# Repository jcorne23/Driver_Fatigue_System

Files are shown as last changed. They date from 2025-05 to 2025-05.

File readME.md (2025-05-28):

# Driver Fatigue System

An integrated driver monitoring system using OpenCV and dlib on a Raspberry Pi to track fatigue through eye and mouth aspect ratios, calculating a running fatigue score based on blink and yawn patterns. The ESP32-CAM streams live video over a custom webserver and displays real-time fatigue data via OLED. An onboard MQ3 sensor supports alcohol detection through a guided breathalyzer test, calibrated using controlled samples and baseline readings. A Flask server coordinates system behavior and enables mobile-based interaction, including optional emergency alert triggers—no internet required. Each respective folder has the code associated with each device with the inclusion of schematics and PCB files. Made and designed by Julio Cornejo and Vincent Ng. 

- [Design Document (PDF)](docs/design_document.pdf)
- [Engineering Notebook](docs/engineering_notebook.md)
- [Final Paper (PDF)](docs/final_report.pdf)

                                                Click the thumbnail to watch the demo!
  
 Click to watch demo (https://drive.google.com/file/d/1akUV6YvoVE6YVaj2TsC6vIiu5VjOl5T-/view?usp=sharing)

- [Video Demo 2](https://drive.google.com/file/d/1_dD5bf3DfNFZJkOF3wCcVmGohEKaDvxr/view?usp=sharing)

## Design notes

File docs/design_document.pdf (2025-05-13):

# Driver Fatigue System

## ECE445 Design Document - Spring 2025

Project # 76
Julio Cornejo
Vincent Ng

Professor: Arne Fliflet
TA: Maanas Agrawal

## Contents

Subsystem 1: Blood Alcohol Concentration System

### 1. Introduction

Problem:
When driving for prolonged amounts of time, some key body movements and facial changes can be made due to drowsiness. The drowsiness, if unmonitored, can pose dangerous conditions for other drivers and the drivers themselves. Intoxication while driving is also a rampant issue; there is no universal breathalyzer that prohibits driving based on BAC. I propose this device that uses facial recognition, eye-level detection sensors, and cameras to detect symptoms of fatigue along the road while also prohibiting intoxicated drivers from proceeding to drive. This device can monitor head position, yawns, and register long blinks. It can also track the driving duration and eventually register all these symptoms if it detects fatigue. Once enough triggers are set, an app interface can assess your tiredness or driving incapability via WiFi transmission. It can suggest and locate the nearest rest stop or call emergency contacts (set by the user). When specific drowsiness scores are reached, the user's BAC and live drowsiness rating will be displayed with in-house buzzer systems.

Solution:
The system revolves around an algorithm that makes use of a variety of sensors and cameras. One is a breathalyzer that measures the blood alcohol concentration of the driver. Using the software, we monitor the live value and set triggers to call emergency contacts and monitor until a safe concentration for resumable driving. Drowsiness and tiredness can be detected in various ways ranging from yawn frequency, long blinks, and head tilts. They happen suddenly. Most traditional cars use your position in a lane to track tiredness. Tracking head movement and analyzing the face for more key indicators precisely provides more information that can be essential to identify when a driver needs to step away from the wheel and request a ride elsewhere. The PCB can be housed in a small, compact shape like a cube that sits over any dashboard with detachment features to trigger the BAC sensor correctly.

Visual Aid:

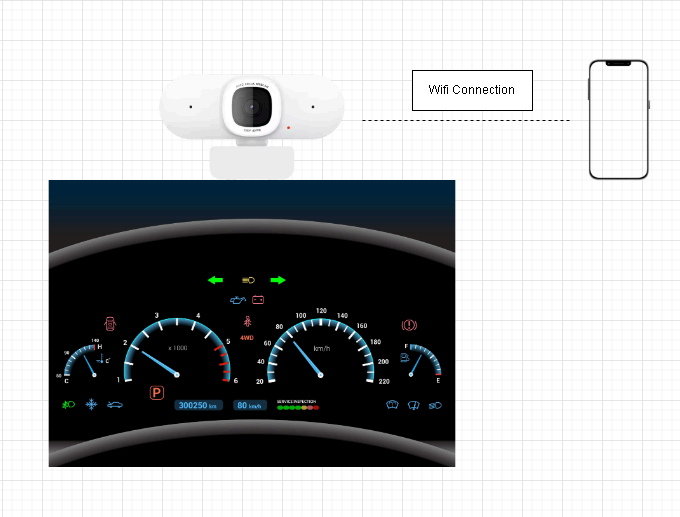
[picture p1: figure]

S
Figure 1: Simple Device Overview High-Level Requirements:
- Driver Inactivity Detection Accuracy: The system must detect eye closure and blink duration with at least 90% accuracy, using an EAR threshold of 0.2 for detecting closed eyes and registering blinks that last ≥15 frames as prolonged closures. The false positive rate for open eyes must remain below 5%.
- BAC Measurement Precision: The device must measure Blood Alcohol Concentration (BAC) with an accuracy of ±1% BAC.
- User Interface Accessibility: The system must provide a mobile/web-based interface that updates drowsiness and BAC data in real-time (latency ≤1 second) and helps users contact emergency contacts within 5 seconds when the drowsiness score surpasses a certain threshold.

### 2. Design

Physical Design:
The physical design of our device will be similar to that of a driver facing dash cam. The housing of our design will be a rectangular box made out of plastic, with cutouts for the camera module, display, led, and breathalyzer tube. There will also be a mounting mechanism for the device so that it can sit securely on the drivers dashboard. In the current time frame of the project, we are not yet at the stage of having a prototype built, but once we do, an image will be attached here for reference.

Block Diagram:

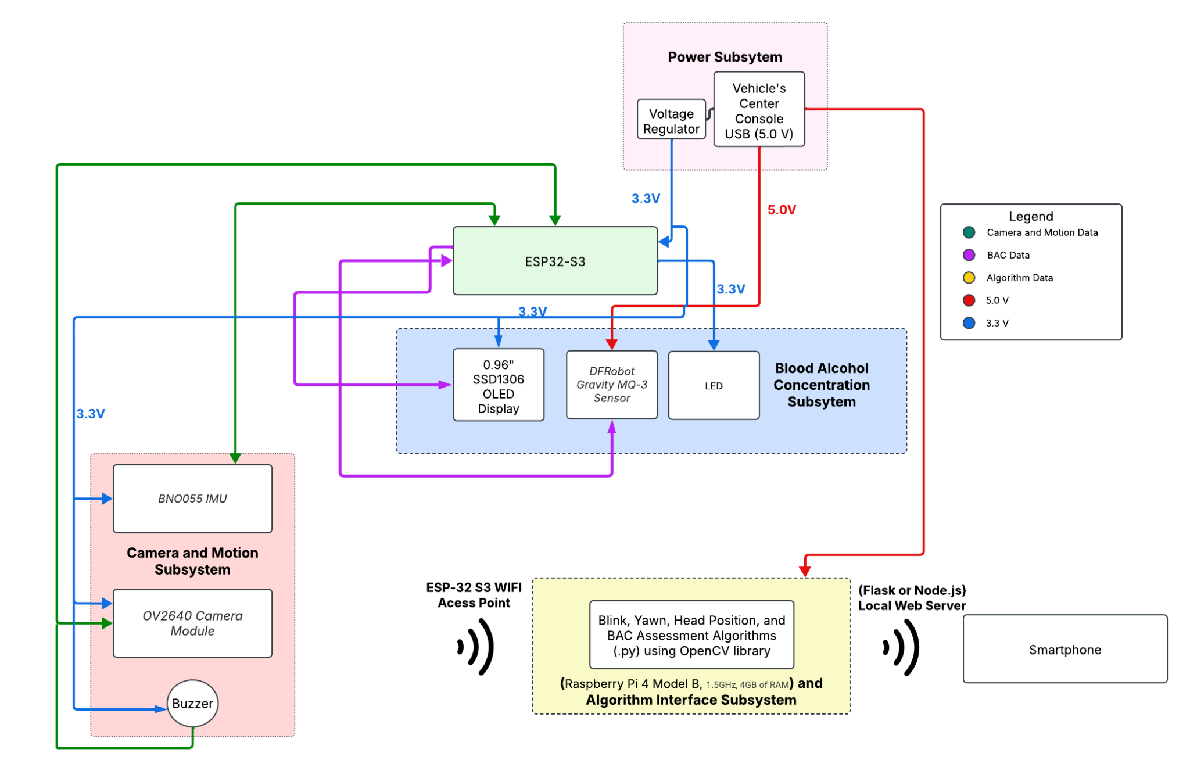
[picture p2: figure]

Figure 2: Diagram of How Each Subsystem is Connected

Subsystem Overview:

Subsystem 1: Blood Alcohol Concentration System
Overview:
The functionality of this subsystem revolves around the MQ-3 breathalyzer sensor responsible for measuring the BAC of a potential driver. Accompanying the sensor is logistical device tools such as a display and LED. This module is connected to the ESP32 microcontroller and communicates directly with our designed algorithm for an automated emergency notification system if intoxication is detected. The BAC will also be locally displayed on the unit's OLED screen. A light will light blue when the device is ready to test an individual’s BAC.

Requirements:
- The device must measure Blood Alcohol Concentration (BAC) with an accuracy of ±0.01% BAC, within a detection range of 0.00% - 0.20% BAC.
- The device must ensure the baud rate transmission is 9600 for the MQ-3’s functionality.
- The LED accurately reflects the readiness and warm-up time of the MQ-3 to provide accurate measurements.

Requirements and Verification Table:
Requirements | Verification
- The device must measure BAC with an accuracy of ±0.01% BAC within a detection range of 0.00% - 0.20% BAC. | ● Perform calibration tests using known alcohol concentrations and compare readings with a certified breathalyzer. ● Cross-checking each of the individual MQ-3 sensors since we ordered a few for faultiness.
- The device must maintain a baud rate of 9600 for MQ-3 communication. | ● Monitor serial transmission using an oscilloscope to verify correct baud rate operation.
- The LED should accurately reflect the readiness and warm-up time of the MQ-3. | ● Measure time from power-on to ready-state using a stopwatch and validate against the MQ-3 datasheet specifications.

Subsystem 2: Power System
Overview:
Our primary power source for our power subsystem comes directly from a car's center console. Most cars have USB ports that provide 5V of power. Coupled with a voltage regulator to step down to 3.3V, we can power our ESP32 and sensor/camera modules. The MQ-3 is powered directly by the 5V source.

Requirements:
- Maintain overall voltage stability within a tolerance of 0.1V (+/-).
- Successful step-down conversion to 3.3V for smooth operation of the BNO055 IMU (Head position sensor), OV2640 Camera Module, SSD1306 OLED Display, and LED.
- Must provide consistent and stable 5V to operate the MQ-3’s critical sensor.

Requirements and Verification Table:
Requirements | Verification
- Maintain overall voltage stability within a tolerance of ±0.1V. | ● Measure voltage fluctuations using a digital multimeter (DMM) under different load conditions.
- Ensure successful step-down conversion to 3.3V for all necessary components. | ● Use a DMM to verify stable 3.3V output under normal operating conditions.
- Provide a consistent and stable 5V output for MQ-3 operation. | ● Test voltage stability under varying load conditions and monitor power fluctuations using an oscilloscope.

Subsystem 3: Camera and Motion System
Overview:
This subsystem is the most critical component for sensing fatigue. Both sensors, BNO055 IMU for head movement and OV2640 Camera Module for eye blink and yawn detection, are essential inputs for our computer vision algorithm; both sensors are powered by a 3.3V power source and interact and transmit data directly to the ESP32. A buzzer is provided for temporary alertness in emergency-level drowsiness.

Requirements:
- Capable of capturing images with sufficient clarity for detecting blinks and yawns.
- To ensure real-time processing, the camera should interface with the ESP32 and quickly transmit image data via WiFi to the Raspberry Pi.
- The camera should support JPEG image compression for efficient data transfer.
- Minimum image resolution: 640x480 pixels and frame requirement of 30fps.
- Non-intrusive (low dB) buzzer and alert-focused sound.

Requirements and Verification Table:
Requirements | Verification
- Capture images with sufficient clarity to detect blinks and yawns. | ● Evaluate image resolution and sharpness using controlled lighting conditions. ● Sample test of an individual blinking X amount of times in a tets period 60 sec. Compare results with algorithm testing.
- Camera must interface with ESP32 and transmit data via WiFi with minimal latency. | ● Measure transmission delay using a network packet analyzer. ● Compare the speed and algorithm running process with I2C connection before testing with WiFi.
- Support JPEG image compression for efficient data transfer. | ● Verify image file sizes and compression ratios using software analysis.

- Maintain a minimum resolution of 640x480 pixels and 30fps frame rate.
- Capture and analyze sample frames to confirm compliance with the required resolution and frame rate.
- Buzzer should emit a non-intrusive alert sound.
- Measure buzzer sound levels in decibels (dB) using a sound meter. Place the nozzle of the sound meter above the encaving of the active buzzer.
- Most active buzzers can be lowered by attaching a resistor using the correct amount of resistance. Validate with a 1k, 10k, etc. for the optimal db count using a sound meter.

Subsystem 4: Algorithm and User Interface Subsystem
Overview:
This subsystem will handle the processing of all sensor data, run the necessary algorithms to assess drowsiness levels based on eye blink frequency, head movements, and breathalyzer readings, and display the results on a web app accessible from a smartphone. It will
communicate wirelessly with the ESP32 microcontroller via WiFi using a client-server access point connected to the Raspberry Pi to receive real-time sensor and camera data. The algorithm will analyze the data, calculate the drowsiness level, and send this information to the web app via another access point, a web-server host using Flask or, potentially, Node.js as our framework. Using WiFi once more, we can display and manipulate all the data for analytics on the smartphone. The web app will provide a real-time drowsiness score to the user and display analytics.

Requirements:
- Using an efficient algorithm, the system must calculate a fair drowsiness score from real-time data (eye blinks, head movement, BAC levels), providing instant feedback on driver fatigue.
- The ESP32 should transmit drowsiness data via WiFi with a minimum baud rate of 9600 bps.
- The web app should provide real-time feedback on the driver’s drowsiness score, display analytics (e.g., blink frequency, head movement), and send alerts when fatigue levels are critical.

- The system must log drowsiness data for historical analysis and send push notifications or emergency contact alerts when the drowsiness score exceeds a defined threshold. Pi Link (https://www.digikey.com/en/products/detail/raspberry-pi/SC0194(9)/10258781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)

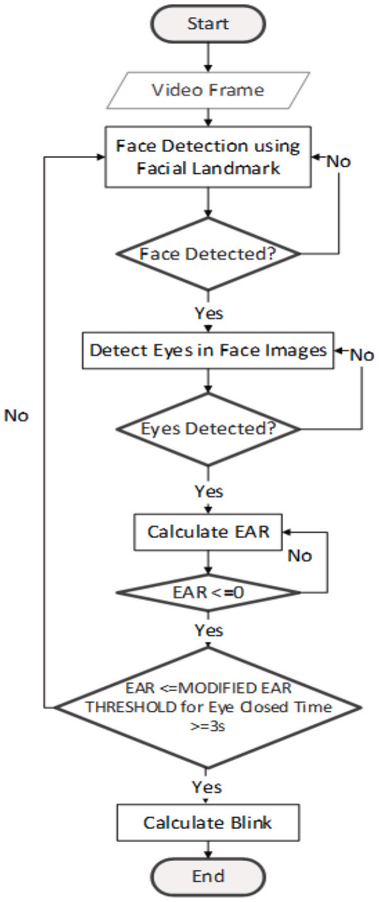
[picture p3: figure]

Figure 3: Flow Chart of EAR algorithm

Requirements and Verification Table:
Requirements | Verification
- Calculate a real-time drowsiness score based on sensor inputs. | ● Validate computed scores against manually analyzed fatigue behavior datasets. ● For test subjects, we can have a self-reported driving quiz where the user assesses a level where they feel incapable
- ESP32 must transmit drowsiness data via WiFi with a baud rate of at least 9600 bps. | ● Monitor WiFi transmission rates using a network packet analyzer.
- Web app should provide real-time
feedback on drowsiness score and analytics.
- Conduct usability tests to ensure data is displayed with minimal delay.
- A user should be able to query into our database to see the times a certain score of their choosing is submitted during their driving times.
- System should log drowsiness data and send emergency alerts when a defined threshold is exceeded.
- Simulate drowsiness conditions and verify proper alert generation and logging.
- Use Twilio API and simulate a call to ourselves via

Tolerance Analysis:
One of this project's most critical and challenging components is the accurate detection of eye closure and blink duration using EAR. The system must reliably differentiate between normal blinking and drowsiness-induced prolonged eye closures while accounting for environmental factors such as low lighting, camera angle variations, and false detections. Reliable measurements are crucial as not to falsely alert drivers when driving on the road.
The Eye Aspect Ratio formula is given below:

P1-P6 are the eye landmarks detected by the OV2640 camera module

We can set the EAR threshold to:
Eyes open: 0.2-0.3
Eyes partially closed: 0.15-0.2
Eyes closed: < 0.15
However, these thresholds are not set in place and can be adjusted once the algorithm testing begins so that we can implement a more refined threshold.
Given our EAR thresholds, we can also register blinks with these conditions:
EAR drops below 0.2 for three consecutive frames (assuming a 30 FPS camera feed).
If EAR remains below 0.2 for more than 15 frames, it is flagged as a sign of drowsiness.

Tolerance Analysis Considerations:
Component Accuracy and Environmental Factors:

Camera Resolution and Precision:
The OV2640 camera module has a resolution of 640x480 pixels at 30 FPS, but low-light conditions may affect its accuracy.
The sensor has an approximate accuracy variance of ±5% in detecting key facial landmarks due to environmental lighting and head orientation.

Measurement Noise and Latency:
EAR calculations rely on landmark detection accuracy, which may fluctuate due to camera latency (typically 10-20 ms per frame under normal conditions).
Noise filtering techniques (e.g., median filtering) will be used to smooth EAR readings to reduce variability.

EAR Threshold Tolerance:
A deviation of ±0.02 EAR from the expected threshold could lead to false positives or missed detections.
A key risk is misclassifying normal long blinks or head tilts as drowsiness. Therefore, we can introduce an adaptive threshold based on the driver's historical blink patterns, adjusting the EAR threshold dynamically.

Weighted Drowsiness Scoring Model:
This is our scoring model that is designed to improve drowsiness detection accuracy by incorporating multiple fatigue indicators. Instead of relying solely on blink duration or frequency, this model assigns different weight values to various fatigue-related behaviors, such as yawning and head tilting, based on their severity and impact on alertness. By aggregating these factors into a single score, the system can more accurately differentiate between temporary fatigue and actual drowsiness. This approach minimizes false positives while ensuring that prolonged drowsiness patterns trigger necessary alerts, making the system more reliable for real-world driving conditions. Whenever a certain drowsiness score threshold is reached, the system will contact the driver’s emergency contact.

The drowsiness score is calculated using a weighted formula shown below:
Assume we monitor over a 60-second window and detect the following:
- Blink Duration: 6 long blinks → High risk
- Blink Frequency: 20 blinks → Moderate risk
- Yawns Detected: 4 yawns → High risk
- Head Tilt Angle: 30° tilt for 5+ sec → Moderate risk
- Head Nods: 2 detected → Low risk

Now, applying the weights that are currency variable and are going to be changing :

Drowsiness Score = (6×4.2) + (20×1.0) + (4×7.5) + (1×10) + (2×5) = (6×4.2) + (20×1.0) + (4×
7.5) + (1×10) + (2×5) = 25.2+20+30+10+10=95.2= 25.2 + 20 + 30 + 10 + 10 = 95.2=25.2+20+30+10+10 = 95.2

### 3. Cost

Cost Analysis:
Note that we are considering the cost of the items with the retail price where we acquired the part, excluding ECE discounts.
Part | Manufacturer | Quantity | Price | Subsystem
Raspberry Pi 4 Model B 2GB | Raspberry Pi Ltd | 1 | $53.99 | Algorithm and Interface
Micro-HDMI Male to HDMI Female Adapter | Microware | 1 | $6.16 | Algorithm and Interface
32GB MicroSD Card | Samsung | 1 | $13.05 | Algorithm and Interface
ESP32-S3 Development Board | HiLetgo | 1 | $16.53 | Algorithm and Interface
OV2640 Camera Module | STMicroelectronics | 1 | $11.99 | Camera and Motion
Active Piezo Buzzer Alarm | GFORTUN | 1 | $0.89 | Camera and Motion
MQ3 Alcohol Sensor Module | Reland Sun | 1 | $2.67 | BAC Concentration
0.96" SSD1306 OLED LCD | HiLetgo | 1 | $6.99 | BAC Concentration
LED | HiLetgo | 1 | $0.89 | BAC Concentration
LD117 Voltage Regulator | STMicroelectronics | 4 | $0.80 | Power Subsystem
Total | | | $116.36

Our project has a heavy computation component relying on algorithm creation and data transfer via WiFi. For this reason, many of the estimated labor hours involve client-server setup, so the ESP-32 and the Pi can efficiently and wirelessly communicate. The algorithms will require extensive image processing, so searching and modifying a functional algorithm is one of the largest time-sinks. Assuming an hourly-paid entry-level engineer position, we take an hourly pay of $45. With a rough estimate of 310 hours based on the schedule and planning, our costs come out to:

Total Cost: Labor Cost + Part Cost = ((310 hours) x ($45) ) + $116.36 = $14066.36

### 4. Schedule

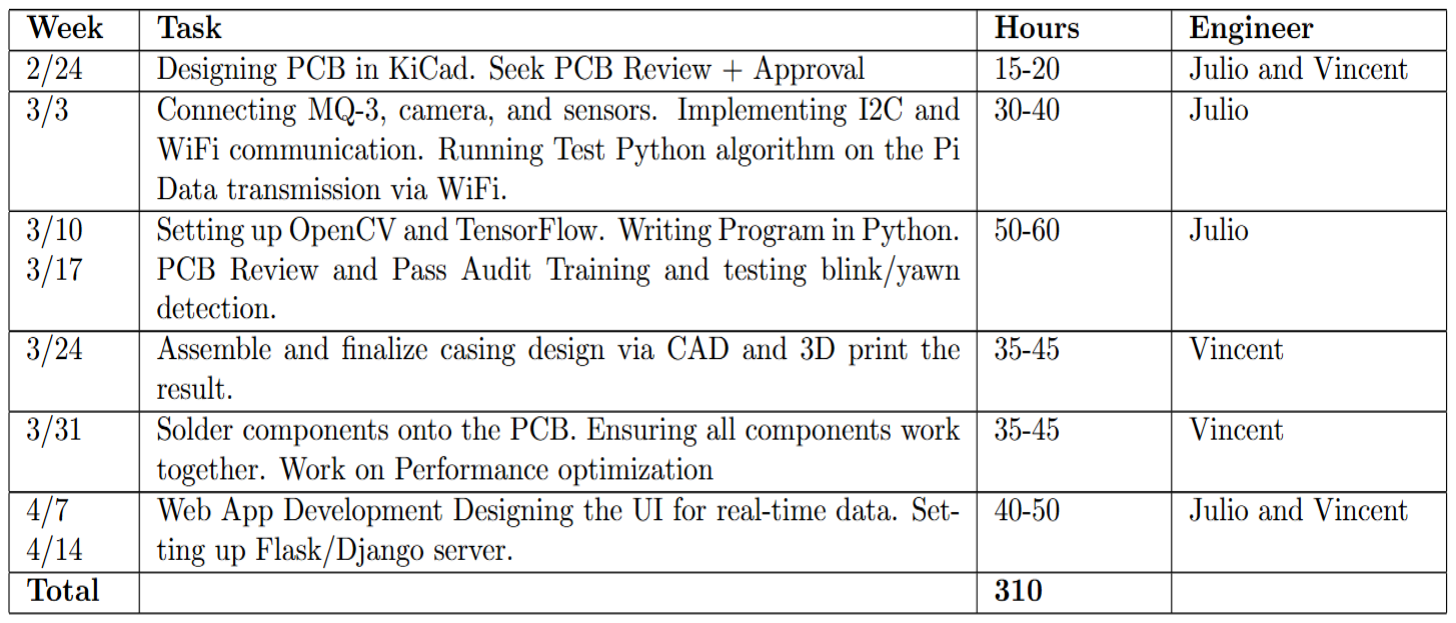
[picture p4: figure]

### 5. Ethics and Safety

Our project's main ethical and safety concerns are privacy and data security.
The system collects sensitive biometric data, including facial recognition patterns, eye movement, and breathalyzer readings. According to the ACM Code of Ethics (Principle 1.6: Respect Privacy), developers must ensure that user data is stored securely and only accessed for its intended purpose. To mitigate potential privacy concerns:
Data will be processed locally on the ESP32-S3 or Raspberry Pi, avoiding unnecessary cloud storage. Encrypted communication protocols (e.g., HTTPS, TLS) will transmit data to the mobile application.

Another ethical concern highlighted by IEEE is Principle 2: Avoid Harm to Others, emphasizing that systems must be designed to avoid discrimination or bias based on race, gender, or disability. We will train our model on a diverse dataset to ensure fairness, including individuals of different ethnicities, backgrounds, and facial features. Not only that, but the EAR threshold will also be adjustable for individuals, allowing for an individualized experience.

Since our device also has a miniature built-in display, we have decided to keep it as minimal as possible to uphold safety guidelines and maintain a safe driving experience. Alerts, buzzer warnings, and the user interface must be designed to minimize distractions.
According to NHTSA guidelines, visual displays should be simple and non-intrusive.
Alerts should not require extended interaction from the driver while operating the vehicle. The buzzer should produce audible but non-alarming signals to avoid panic responses.

### 6. Citations and References

Dewi, C., Chen, R.-C., Jiang, X., & Yu, H. (2022, April 18). Adjusting eye aspect ratio for strong eye blink detection based on facial landmarks. PeerJ. Computer science. https://pmc.ncbi.nlm.nih.gov/articles/PMC9044337/

Pandey, D. (2021, April 21). Eye aspect ratio(ear) and drowsiness detector using dlib. Medium.
https://medium.com/analytics-vidhya/eye-aspect-ratio-ear-and-drowsiness-detector-using -dlib-a0b2c292d706 (https://medium.com/analytics-vidhya/eye-aspect-ratio-ear-and-drowsiness-detector-using-dlib-a0b2c292d706)

Raspberry pi documentation - getting started. Raspberry pi documentation. (n.d.). https://www.raspberrypi.com/documentation/computers/getting-started.html

Shekari Soleimanloo, S., Wilkinson, V. E., Cori, J. M., Westlake, J., Stevens, B., Downey,
L. A., Shiferaw, B. A., Rajaratnam, S. M. W., & Howard, M. E. (2019, September 15). Eye-blink parameters detect on-road track-driving impairment following severe sleep deprivation. Journal of clinical sleep medicine : JCSM : official publication of the American Academy of Sleep Medicine. https://pmc.ncbi.nlm.nih.gov/articles/PMC6760410/

Ucl. (2022, May 6). Blink and you miss it!. UCL News. https://www.ucl.ac.uk/news/2005/jul/blink-and-you-miss-it

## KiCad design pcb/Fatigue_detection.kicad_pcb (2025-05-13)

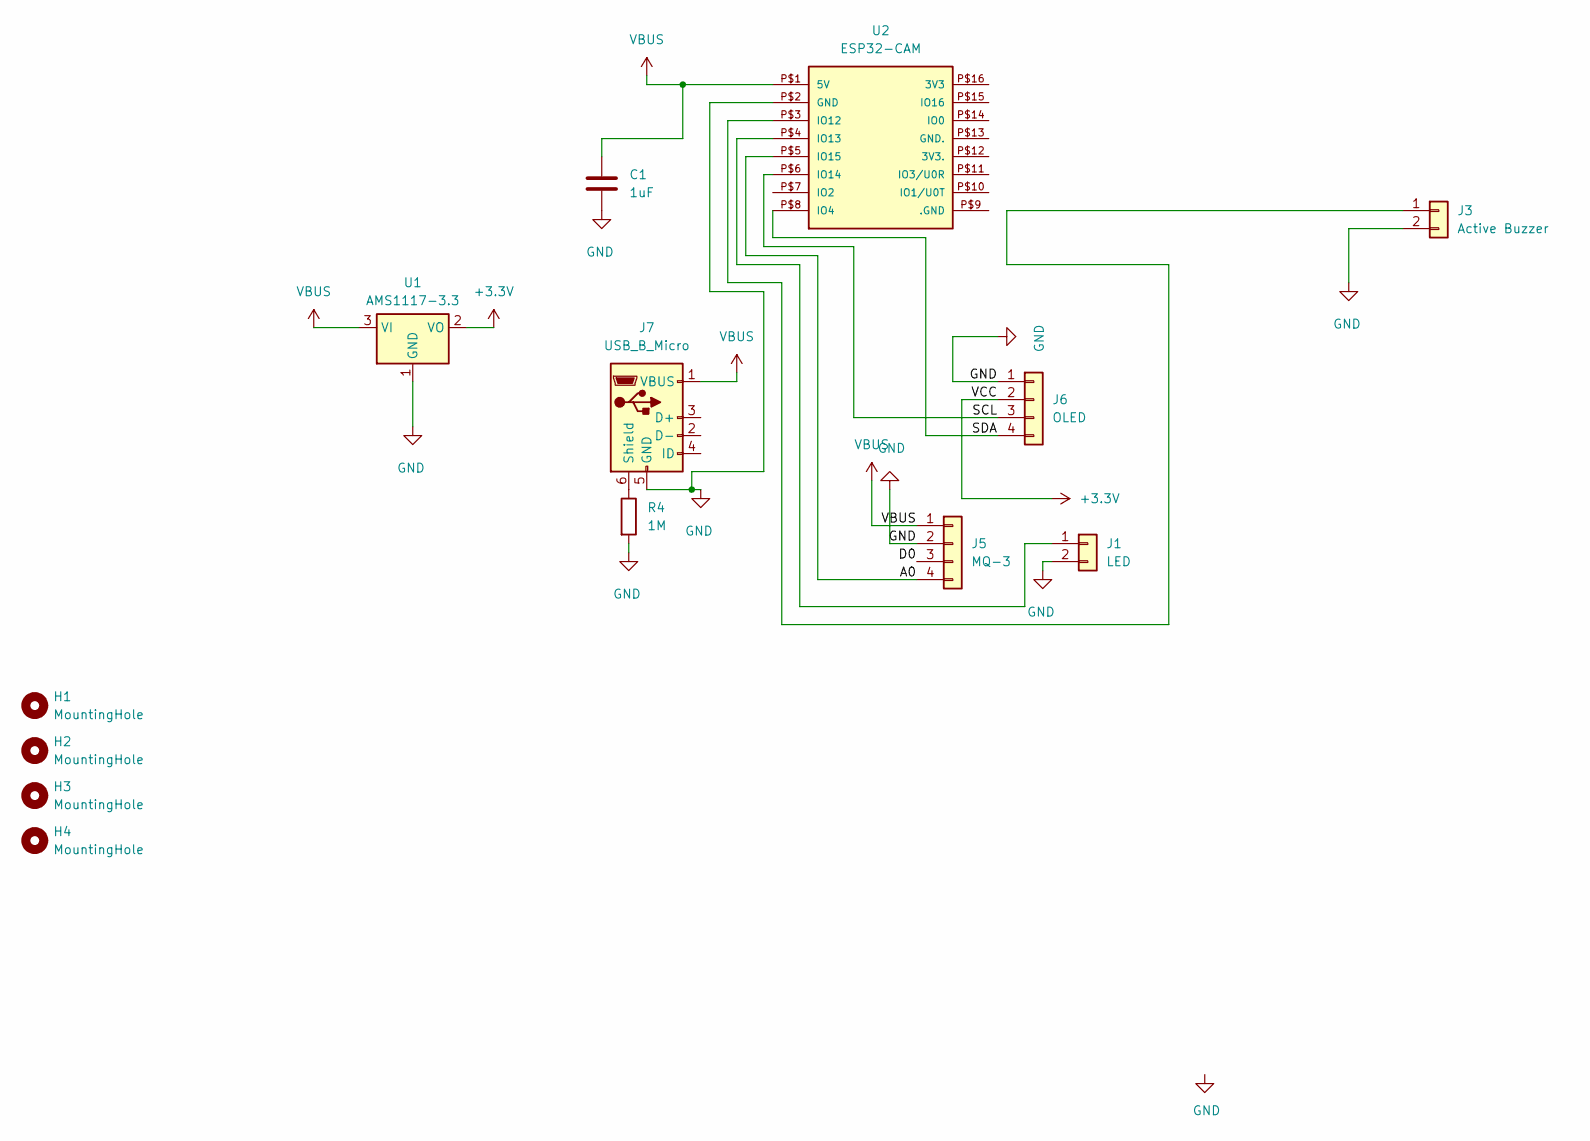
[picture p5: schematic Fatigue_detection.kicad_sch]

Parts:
C1: 1uF; C_0805_2012Metric_Pad1.18x1.45mm_HandSolder
H1, H2, H3, H4: MountingHole; MountingHole_3.2mm_M3
J1: LED; Molex_KK-254_AE-6410-02A_1x02_P2.54mm_Vertical
J3: Active Buzzer; Molex_KK-254_AE-6410-02A_1x02_P2.54mm_Vertical
J5: MQ-3; Molex_KK-254_AE-6410-04A_1x04_P2.54mm_Vertical
J6: OLED; Molex_KK-254_AE-6410-04A_1x04_P2.54mm_Vertical
J7: USB_B_Micro; USB_Micro-B_Amphenol_10118194-0001LF_Horizontal
R4: 1M; R_0805_2012Metric_Pad1.20x1.40mm_HandSolder
U1: AMS1117-3.3; SOT-223-3_TabPin2
U2: ESP32-CAM

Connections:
+3.3V: J6.2, U1.2 (VO)
/A0: J5.4, U2.P$5 (IO15)
/D0: J5.3
/SCL: J6.3, U2.P$6 (IO14)
/SDA: J6.4, U2.P$8 (IO4)
GND: C1.2, J1.2, J3.2, J5.2, J6.1, J7.5 (GND), R4.2, U1.1 (GND), U2.P$2 (GND); also elsewhere on the board
unnamed: J1.1, U2.P$4 (IO13)
unnamed: J3.1, U2.P$3 (IO12)
unnamed 8: J7.6 (Shield), R4.1; also elsewhere on the board
VBUS: C1.1, J5.1, J7.1 (VBUS), U1.3 (VI), U2.P$1 (5V); also elsewhere on the board

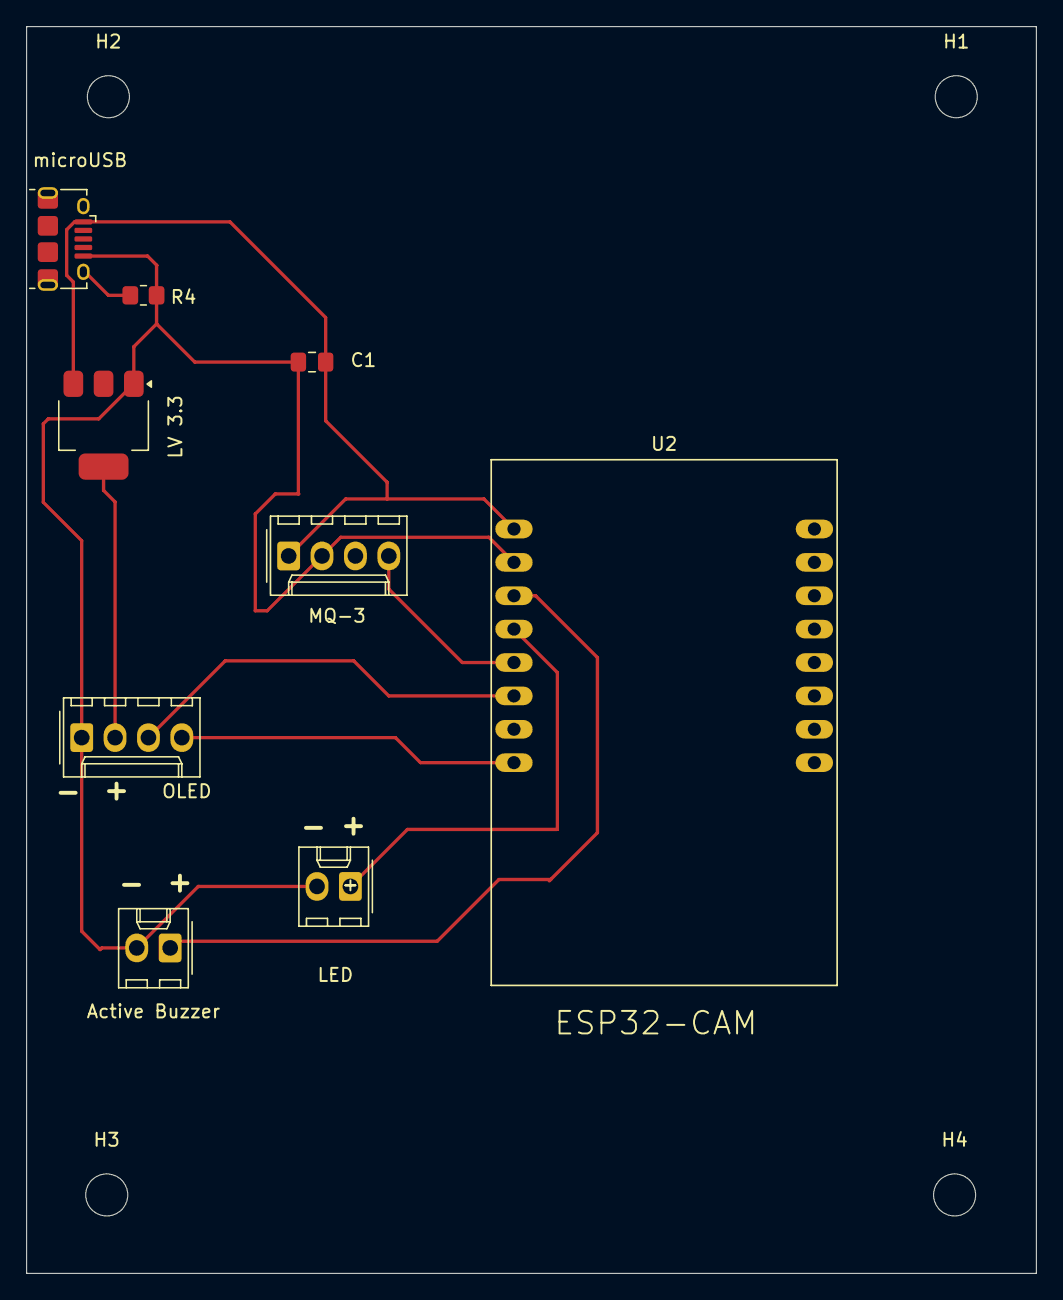
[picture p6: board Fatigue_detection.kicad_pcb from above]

Board: 2 copper layers, 76.8 x 94.9 mm, 13 parts (0 on the bottom side), 9 nets.

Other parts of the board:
microUSB: USB_B_Micro; USB_Micro-B_Amphenol_10118194-0001LF_Horizontal

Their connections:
GND: microUSB.5 (GND); also elsewhere on the board
unnamed 8: microUSB.6 (Shield); also elsewhere on the board
VBUS: microUSB.1 (VBUS); also elsewhere on the board

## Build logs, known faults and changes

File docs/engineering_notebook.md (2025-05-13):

# Driver Fatigue System - Weekly Progress Log
Week 1 Feb 10 - 14 | General Research and Proposal Writing
=========================================================

Sleep-deprived driving is an underappreciated but dangerously common problem. On a recent drive back home from Illinois in my Mustang GT, I experienced firsthand just how severe fatigue behind the wheel can become. Despite having lane assist and blasting music with caffeine in hand, I caught myself swerving repeatedly—my eyelids growing heavier, my focus slipping. There were stretches of road where my eyes were closed for what felt like forever, and I realized I was becoming a serious danger to myself and everyone around me. Rest stops felt untrustworthy, and I had no meaningful way to assess whether I was safe to continue driving.
This experience exposed a real and urgent gap in driver wellness awareness, especially when driving alone for long distances. What I truly needed wasn’t more coffee or loud music; I needed an objective, real-time system that could monitor my condition and help me make smarter decisions before it was too late.
This inspired the development of the Driver Fatigue System—a multi-modal platform designed to track signs of drowsiness, monitor facial fatigue cues like prolonged blinks or yawns, and even detect signs of intoxication. By combining computer vision, real-time feedback, and onboard alerts, this system aims to support drivers in staying safe, informed, and aware of their physical state while on the road.





After identifying the dangers of drowsy driving from personal experience, we began designing a system that could monitor a driver’s alertness in real time. To do this, we needed a mix of physical sensors and wireless communication to assess wellness and deliver feedback quickly. The flowchart we developed became the blueprint for this vision, outlining how each component—camera, sensors, display, and servers—would connect and operate together.
At the heart of the system is the ESP32-S3, which collects sensor data and controls outputs like an OLED display, buzzer, and LED. Powered through a car’s USB port and regulated to 3.3V using an AMS1117, the ESP32 also connects to a DFRobot MQ-3 alcohol sensor and an OV2640 camera module. We initially planned to use a motion sensor (BNO055 IMU), but removed it after determining it was unnecessary.
To handle intensive tasks like image processing, we offloaded blink and yawn detection to a Raspberry Pi 4 running Python scripts and OpenCV, hosted on a Flask web server. Every 30 seconds, the Pi calculates a fatigue score and sends it back to the ESP32 or browser interface. A smartphone hotspot serves as the local network, assigning IPs to both the Pi and ESP32 for fast, local communication.
This system balances local device feedback with server-side intelligence, creating a responsive tool to help drivers assess their condition before it becomes dangerous, all sparked by one tired night on the road.



We begin to seek out parts from the ECE building and using our project funds to outsource on Amazon the items unavailable to us in the building. 

Week 2 Feb 17 - 21 | Project Proposal Review + Inital Design Stage
===================================================================



This schematic represents our initial hardware mockup, developed during the early planning phase of the project. At this stage, we designed around an ESP32-DEVKITC-32E and prioritized including a USB-C connector for modern power delivery and convenience. Power from the USB-C port was stepped down to 3.3V using an AMS1117 regulator to supply the microcontroller and all peripherals. Key components such as the MQ-3 alcohol sensor, OLED display, LED, and buzzer were mapped out and connected directly to available GPIO pins. This early layout gave us full control over pin assignments and served as a foundational reference for system integration.



This image shows our initial PCB layout in KiCad, where we encountered several critical design oversights. One major issue was the USB-C port footprint, which was placed away from the board edge—making it physically unusable for cable connection. At this stage, we were still relying on a Molex-style connection scheme for the camera and sensors, which added wiring complexity. We used part libraries and footprint imports from Digi-Key to populate our schematic and layout quickly, but overlooked mechanical placement and enclosure fit. Despite its flaws, this version helped us become more familiar with PCB workflow and informed our corrected final revision.

During development, we realized the original camera configuration using Molex-style I2C connectors was not reliable or practical for repeated prototyping. This led us to explore alternative connection methods, ultimately choosing a camera strip connector similar to those used in commercial ESP32-CAM modules. The transition required sourcing a compatible connector and verifying pin alignment and signal integrity. This change greatly improved physical stability and reduced the chance of misalignment or connection failure. It also simplified integration with our PCB and reduced debugging time during testing.

Week 3 Feb 24 - 28 | Initial Design Completed
================================================

Initial Sensor Testing 



We successfully got the MQ3 alcohol sensor working with the ESP32-DevKitC on a breadboard setup. By configuring GPIO 34 as an analog input and adjusting the resolution to 12 bits, we were able to read and convert raw ADC values into voltage. The live readings confirmed stable and responsive sensor output, validating our connection and code setup.



This OV2640 camera module was ultimately unusable in our system due to missing documentation and incomplete pin functionality. Notably, it lacks an exposed XCLK (external clock) pin, which is required to drive the camera sensor with a 10–20 MHz clock signal from the ESP32. Without this input, the module cannot be initialized or stream image data properly. Additionally, there were no available datasheets or verified user reviews to validate the pinout or confirm signal compatibility, making debugging nearly impossible. As a result, we replaced it with a more standardized ESP32-CAM board that included proper XCLK routing and a proven working configuration.



This schematic reflects the updated design in which we moved away from the ESP32-DevKitC and opted for a more compact and solder-friendly approach. We integrated a micro-USB port for easier power access and enclosure compatibility, using an AMS1117 regulator to supply 3.3V to the system. The selected ESP32 module connects via a flexible ribbon-style interface, simplifying the connection to the camera and reducing the number of manual jumper wires required. This change improved both assembly time and reliability, enabling a cleaner and more maintainable final hardware layout.

Week 4 Mar 3 - 7 | Teamwork Evaluation + Design Document + Inital Subsystem Implementation
========================================================================



This is our revised PCB design, created after addressing the limitations of our initial prototype. In this version, we correctly positioned the micro-USB connector along the edge of the board to ensure full cable compatibility and structural alignment. The layout was reworked for improved functionality and cleaner trace routing to support components like the MQ-3 sensor, OLED display, buzzer, and LED indicator. This version also finalized mounting holes and better spacing to accommodate enclosure constraints and mechanical stability. Overall, the design reflects a more production-ready and functional board that integrates all project subsystems reliably.



To get I2C working on the ESP32-CAM, we had to manually assign pins since it doesn’t have dedicated I2C hardware lines. We selected GPIO 15 for SDA and GPIO 14 for SCL, then initialized a TwoWire object on bus 0. Using the Adafruit SSD1306 library with these custom-defined pins, we were able to successfully communicate with the OLED display. This setup allowed reliable screen output without interfering with the camera or WiFi, which often share key GPIOs on the ESP32-CAM.

Week 5 Mar 10 - 14 | Breadboard Demos
===================================================================



A key breakthrough in our development came thanks to Vincent, who successfully installed the dlib library on the Raspberry Pi—a process known to be notoriously difficult due to its dependency on CMake and lengthy compile time. After having the blink and yawn detection logic running reliably on his local machine, Vincent worked through multiple build errors and optimized configurations to get dlib up and running on the Pi. Once installed, we were able to port over his ear_detection.py script, allowing real-time Eye Aspect Ratio (EAR) and Mouth Aspect Ratio (MAR) calculations to execute directly on the Pi. This milestone meant our fatigue detection could now operate independently on the embedded system without relying on external computing resources.

The code Vincent suggested for EAR detection based on landmarks

Week 6 Mar 17 - 21 | Spring Break
=================================================



This image captures a crucial moment in our blink detection accuracy testing phase. Using OpenCV and dlib-based facial landmark tracking, we monitored Eye Aspect Ratio (EAR) values in real time to detect both normal and long blinks. The terminal output below logs each blink classification, allowing us to verify detection reliability visually and statistically. This setup was used extensively to fine-tune thresholds and confirm the system's ability to differentiate fatigue-related blink patterns. The annotated camera feed also helped us validate alignment and feature tracking frame-by-frame.

Week 7 Mar 24 - 28 | Research and Building Software
==================================================================================

Endpoint Routing ESP 32 SIDE



UI HANDLER 

POST Receiver 



URI Registration 



The ESP32 server-side HTTP file defines and handles routes for POST-based control of hardware peripherals. In this example, the /flash endpoint is registered using httpd_uri_t, and tied to the flash_toggle_handler function. When a POST request is received, the handler parses the body to determine whether to turn the flashlight (GPIO 4) on, off, or set its brightness to a specific level using PWM. The flash_ui_handler also serves a simple HTML interface that allows manual control from any browser on the network. This implementation worked beautifully, providing low-latency feedback and making the ESP32 both network-controllable and UI-friendly.



During testing, we discovered that enabling WiFi using <WiFi.h> on the ESP32 interfered with analog pin readings, particularly on GPIO 15 used for the MQ3 alcohol sensor. To resolve this, we implemented a physical button that allows the user to disable WiFi before initiating the alcohol sensing routine. Once the button is pressed, the ESP32 disconnects from WiFi, shuts down the radio module, and begins the MQ3 test using analogRead without interference. This solution reliably restored ADC functionality and allowed us to balance network communication with sensor accuracy. It also gave us more control over when and how analog measurements were taken in the broader driver monitoring workflow.

UI 1.1 ESP32 SERVER 



This screenshot shows the original user interface hosted on the ESP32 web server, which was functional but lacked mobile responsiveness. The layout consisted of basic HTML with minimal styling, resulting in small, unaligned buttons and poor scaling on mobile devices. While the core features like flashlight control, MQ3 testing, and session launching worked as intended, the interface was difficult to use on smartphones. This early version served as a proof of concept but highlighted the need for better UI design and CSS styling for improved usability across devices.



This image shows the improved and finalized version of our ESP32 server UI, optimized for mobile use. Compared to the original version, this interface features clearer button spacing, consistent alignment, and more intuitive styling for touchscreen interaction. Buttons are styled with hover effects, color cues, and padding that make each function, like starting a driving session or toggling the buzzer, easy to access on any smartphone. The layout responds well to different screen sizes and maintains readability, addressing the usability issues seen in our first prototype. This polished interface enhances the overall user experience and ties together the system’s core functions in a clean, professional presentation.

Week 8 Mar 31 - Apr 4 | 3rd Round PCB order
==================================================================================

Raspberry Pi Server Versions: 



In this Flask server implementation, we introduced Python's threading module to run the ear_detection.py script in a separate thread. This allowed the Raspberry Pi to continue handling incoming POST requests without being blocked by the long-running image processing task. By offloading the detection script to a background thread, we improved the server's responsiveness and ensured real-time data could still be received and processed concurrently. This was essential for maintaining smooth interaction between the ESP32 and the Pi during live monitoring.



This JavaScript code snippet powers the dynamic front-end behavior of our Raspberry Pi Flask server UI. When POST requests are received at the Pi server, incoming data is stored in arrays such as messages and fatigue_scores. These arrays are then passed to the HTML file, where functions like updateFeed() and updateChart() dynamically render the content using DOM manipulation and Chart.js, respectively. As a result, fatigue event messages appear in real time, and score trends are visualized without needing to refresh the page, creating a seamless, lifelike user experience.

Week 9 Apr 7 - 11 | Final PCB order
==================================================================================



This image shows our finalized prototype demo on a breadboard, featuring the ESP32-CAM connected with the MQ3 alcohol sensor, a button for triggering tests, and an active buzzer for alerts. All components are powered and wired to function together as a cohesive fatigue and BAC monitoring system. The OLED display is not shown here but is mounted inside the final enclosure. This setup was used to validate full system integration before soldering onto the custom PCB.

Week 10 Apr 14 - 18 | Continued Debugging and Research
==================================================================================



This interface serves as the real-time monitoring dashboard for our driver fatigue system. At the top, a scrolling terminal-style feed displays live detection messages such as "Normal blink detected" and "Long blink detected," streamed directly from the Raspberry Pi via POST requests. Below the feed, a line chart titled "Fatigue Score Over Time" visualizes the driver’s calculated fatigue levels, updating automatically in 30-second intervals. The fatigue score is computed based on blink frequency, duration, and other facial markers, and is plotted using Chart.js with a neon green aesthetic to match the terminal theme. Together, the feed and graph provide a responsive and informative snapshot of the driver’s alertness in real time.

Week 11 Apr 21 - 25 | MOCK DEMO
==================================================================================



This image shows one of our key testing sessions, where we evaluated communication latency and data flow across the system. The Raspberry Pi was used to run real-time computer vision algorithms while hosting a local Flask server. The top screen displays the live facial tracking with printed detection logs, while the laptop on the bottom shows the web interface receiving fatigue score updates over time. The ESP32-CAM and MQ3 alcohol sensor were connected via breadboard during this stage to simulate the final hardware behavior. These tests helped us tune the interval for message handling, validate our POST routing, and ensure the entire pipeline, from sensing to interface, responded with minimal delay.

To support multiple peripherals, including the MQ-3 alcohol sensor, an LED indicator, an OLED display, a button interface, and the ESP32-CAM running a WiFi server and camera stream, we initially powered the system with a 5V 1A supply. However, the system exhibited instability during peak load conditions, particularly when both the WiFi module and camera were active, occasionally causing brownouts and spontaneous resets. To address this, we upgraded to a 5V 2.4A regulated source. The estimated current draw was calculated as follows:

Week 12 Apr 28 - May 2 | DEMO WEEK
==================================================================================





This image shows the final PCB implementation with all soldered components and jumper wires securely in place. The ESP32-CAM module is mounted directly onto the board, interfacing cleanly with the underlying traces connected to the OLED, MQ3 sensor, LED, and buzzer. Unlike earlier prototypes that relied heavily on breadboards and loose wiring, this design offers improved electrical stability and structural integrity. The soldered connections ensure robust signal delivery across all subsystems while maintaining a clean and modular layout. This finalized PCB reflects the culmination of our hardware integration efforts and is fully functional as tested with the completed driver monitoring system.

Final Enclosure ready for final demo! Everything is working! 



Week 13 May 5 - 9 | FINAL WEEK WRAPPING UP
==================================================================================

In this week, we made finishing touches to our Final Presentation Slides  
Successfully presented our project to Professor, TAs, and peers

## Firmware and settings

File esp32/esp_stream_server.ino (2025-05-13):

#include "esp_camera.h"
#include <WiFi.h>
#include <Arduino.h>
#include <Wire.h>
#include <Adafruit_GFX.h>
#include <Adafruit_SSD1306.h>



#define CAMERA_MODEL_ESP32_CAM_BOARD
#define MQ3_PIN  15     // PIN FOR THE MQ3
#define LED_FLASH 4     // PIN FOR THE FLASHLIGHT 
#define MQ3_LED_PIN 13  // GPIO 15 controls the external LED (if safe)
#define BUTTON_PIN 2

//OLED DEFINES
#define I2C_SDA 16
#define I2C_SCL 14
TwoWire I2Cbus = TwoWire(0);

// Display defines
#define SCREEN_WIDTH    128
#define SCREEN_HEIGHT   64
#define OLED_RESET      -1
#define SCREEN_ADDRESS  0x3C
Adafruit_SSD1306 display(SCREEN_WIDTH, SCREEN_HEIGHT, &I2Cbus, OLED_RESET);

bool mq3TestStarted = false;  


#include "camera_pins.h"

// ============================
// Enter your WiFi credentials
// ===========================
const char *ssid =  "NETGEAR97";  
const char *password = "slowunit520";

void startCameraServer();

void setup() {
  Serial.begin(115200);
  Serial.setDebugOutput(false);
  Serial.println();
  analogReadResolution(12);
  ledcAttach(4, 5000,8);   // Attach GPIO 4 to channel
  ledcWrite(4, 0);  
  pinMode(BUTTON_PIN, INPUT_PULLUP);
  
  pinMode(12, OUTPUT);
  digitalWrite(12, LOW); // Buzzer starts OFF

  I2Cbus.begin(I2C_SDA, I2C_SCL, 100000);
  Serial.println("Initialize display");

  if(!display.begin(SSD1306_SWITCHCAPVCC, SCREEN_ADDRESS))
  {
    Serial.printf("SSD1306 OLED display failed to initalize.\nCheck that display SDA is connected to pin %d and SCL connected to pin %d\n", I2C_SDA, I2C_SCL);
    while (true);
  }
  Serial.println("Show 'Hello World!' on display");


  camera_config_t config;
  config.ledc_channel = LEDC_CHANNEL_0;
  config.ledc_timer = LEDC_TIMER_0;
  config.pin_d0 = Y2_GPIO_NUM;
  config.pin_d1 = Y3_GPIO_NUM;
  config.pin_d2 = Y4_GPIO_NUM;
  config.pin_d3 = Y5_GPIO_NUM;
  config.pin_d4 = Y6_GPIO_NUM;
  config.pin_d5 = Y7_GPIO_NUM;
  config.pin_d6 = Y8_GPIO_NUM;
  config.pin_d7 = Y9_GPIO_NUM;
  config.pin_xclk = XCLK_GPIO_NUM;
  config.pin_pclk = PCLK_GPIO_NUM;
  config.pin_vsync = VSYNC_GPIO_NUM;
  config.pin_href = HREF_GPIO_NUM;
  config.pin_sccb_sda = SIOD_GPIO_NUM;
  config.pin_sccb_scl = SIOC_GPIO_NUM;
  config.pin_pwdn = PWDN_GPIO_NUM;
  config.pin_reset = RESET_GPIO_NUM;
  config.xclk_freq_hz = 20000000;
  config.frame_size = FRAMESIZE_UXGA;
  config.pixel_format = PIXFORMAT_JPEG;  
  config.grab_mode = CAMERA_GRAB_WHEN_EMPTY;
  config.fb_location = CAMERA_FB_IN_PSRAM;
  config.jpeg_quality = 12;
  config.fb_count = 1;

  if (config.pixel_format == PIXFORMAT_JPEG) {
    if (psramFound()) {
      config.jpeg_quality = 10;
      config.fb_count = 2;
      config.grab_mode = CAMERA_GRAB_LATEST;
    } else {
      config.frame_size = FRAMESIZE_SVGA;
      config.fb_location = CAMERA_FB_IN_DRAM;
    }
  } else {
    config.frame_size = FRAMESIZE_240X240;
#if CONFIG_IDF_TARGET_ESP32S3
    config.fb_count = 2;
#endif
  }

#if defined(CAMERA_MODEL_ESP_EYE)
  pinMode(13, INPUT_PULLUP);
  pinMode(14, INPUT_PULLUP);
#endif

  esp_err_t err = esp_camera_init(&config);
  if (err != ESP_OK) {
    Serial.printf("Camera init failed with error 0x%x", err);
    return;
  }

  sensor_t *s = esp_camera_sensor_get();
  if (s->id.PID == OV3660_PID) {
    s->set_vflip(s, 1);        // flip it back
    s->set_brightness(s, 1);   // up the brightness just a bit
    s->set_saturation(s, -2);  // lower the saturation
  }
  // drop down frame size for higher initial frame rate
  if (config.pixel_format == PIXFORMAT_JPEG) {
    s->set_framesize(s, FRAMESIZE_QVGA);
  }

#if defined(CAMERA_MODEL_M5STACK_WIDE) || defined(CAMERA_MODEL_M5STACK_ESP32CAM)
  s->set_vflip(s, 1);
  s->set_hmirror(s, 1);
#endif

#if defined(CAMERA_MODEL_ESP32S3_EYE)
  s->set_vflip(s, 1);
#endif

// Setup LED FLash if LED pin is defined in camera_pins.h
#if defined(LED_GPIO_NUM)
  setupLedFlash(LED_GPIO_NUM);
#endif

  WiFi.begin(ssid, password);
  WiFi.setSleep(false);

  Serial.print("WiFi connecting");
  while (WiFi.status() != WL_CONNECTED) {
    delay(500);
    Serial.print(".");
  }
  Serial.println("");
  Serial.println("WiFi connected");

  startCameraServer();

  Serial.print("Camera Ready! Use 'http://");
  Serial.print(WiFi.localIP());
  Serial.println("' to connect");




display.clearDisplay();

// Big header
display.setTextSize(2);
display.setTextColor(SSD1306_WHITE);
display.setCursor(0, 0);
display.println("Driver");

display.setCursor(0, 16);
display.println("Fatigue");

display.setCursor(0, 32);
display.println("System");

// Small IP at bottom
display.setTextSize(1);
display.setCursor(0, 56);
display.print("IP: ");
display.print(WiFi.localIP());

display.display();  // Push everything at once

}



void runMQ3Test() {
  pinMode(MQ3_LED_PIN, OUTPUT);

  // Warmup countdown
  for (int i = 1; i <= 15; i++) {
    display.clearDisplay();
    display.setTextSize(2);
    const char* title = "BAC TEST";
    int16_t titleWidth = strlen(title) * 12;
    int16_t titleX = (128 - titleWidth) / 2;
    display.setCursor(titleX, 0);
    display.setTextColor(SSD1306_WHITE);
    display.println(title);

    display.setTextSize(1);
    String warmupStr = "Warmup: " + String(i) + " / 15 sec";
    int16_t warmupWidth = warmupStr.length() * 6;
    int16_t warmupX = (128 - warmupWidth) / 2;
    display.setCursor(warmupX, 36);
    display.println(warmupStr);

    display.display();
    delay(1000);
  }
  digitalWrite(MQ3_LED_PIN, HIGH); 

  // Measurement loop
  for (int i = 0; i < 30; i++) {
    int rawValue = analogRead(MQ3_PIN);
    float voltage = rawValue * (3.3 / 4095.0);

    // Calculate BAC
    float bac = 0.0;
    if (voltage > 1.8) {
      bac = (voltage - 1.8) * (0.20 / (3.3 - 1.8));
      // Optional: Clamp maximum BAC at 0.20
      if (bac > 0.20) bac = 0.20;
    } else {
      bac = 0.0;
    }

    display.clearDisplay();
    display.setCursor(0, 0);
    display.setTextSize(1);
    display.setTextColor(SSD1306_WHITE);
    display.println("MQ-3 Sensor");
    display.print("Raw: ");
    display.println(rawValue);
    display.print("Voltage: ");
    display.print(voltage, 3);
    display.println(" V");

    display.print("BAC: ");
    display.print(bac, 3);  // 3 decimal places
    display.println(" %");

    display.setCursor(0, 56);
    display.print("Sec: ");
    display.print(i + 1);
    display.print(" / 30");

    display.display();
    delay(1000);
  }


  // Final message
  display.clearDisplay();
  display.setCursor(0, 0);
  display.setTextSize(1);
  display.println("MQ3 Test Done");
  display.display();

  digitalWrite(MQ3_LED_PIN, LOW);
}



void loop() {
  if (!mq3TestStarted && digitalRead(BUTTON_PIN) == LOW) {
    delay(50);
    if (digitalRead(BUTTON_PIN) == LOW) {  // Check again after debounce
      Serial.println("Button pressed! Starting MQ3 Test.");

      mq3TestStarted = true;  // Mark that the MQ3 test is now running

      WiFi.disconnect(true);
      WiFi.mode(WIFI_OFF);
      Serial.println("WiFi disconnected.");

      
      runMQ3Test();

      while (true) {
        delay(1000);  // Just freeze here for now (safe)
      }
    }
  }

  delay(10);  // Tiny delay to make the loop CPU-friendly
}

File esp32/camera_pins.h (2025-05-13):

#if defined(CAMERA_MODEL_ESP32_CAM_BOARD)
#define PWDN_GPIO_NUM     32
#define RESET_GPIO_NUM    -1
#define XCLK_GPIO_NUM      0
#define SIOD_GPIO_NUM     26
#define SIOC_GPIO_NUM     27

#define Y9_GPIO_NUM       35
#define Y8_GPIO_NUM       34
#define Y7_GPIO_NUM       39
#define Y6_GPIO_NUM       36
#define Y5_GPIO_NUM       21
#define Y4_GPIO_NUM       19
#define Y3_GPIO_NUM       18
#define Y2_GPIO_NUM        5
#define VSYNC_GPIO_NUM    25
#define HREF_GPIO_NUM     23
#define PCLK_GPIO_NUM     22


#else
#error "Camera model not selected"
#endif

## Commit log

2025-05-13 Uploading ARDUINO IDE ESP FILES
    [partitions.csv]
2025-05-13 PCB files
    [Fatigue_detection.kicad_pcb, Fatigue_detection.kicad_sch]
